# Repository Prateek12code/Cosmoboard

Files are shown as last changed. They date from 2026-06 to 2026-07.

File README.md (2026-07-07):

# Cosmoboard

**Cosmoboard** is a custom 75% mechanical keyboard with an open-top floating-switch design, custom PCB, MX hot-swap support, RGB lighting, and a 3D printed case and plate.

It is designed as a clean V1 keyboard build: simple enough to manufacture, but still custom enough to learn PCB design, keyboard matrices, routing, stabilizer placement, case design, and real hardware assembly.

> Type your ideas into orbit, one key at a time.

---

## Gallery

| PCB | Plate | 3D View |
|---|---|---|
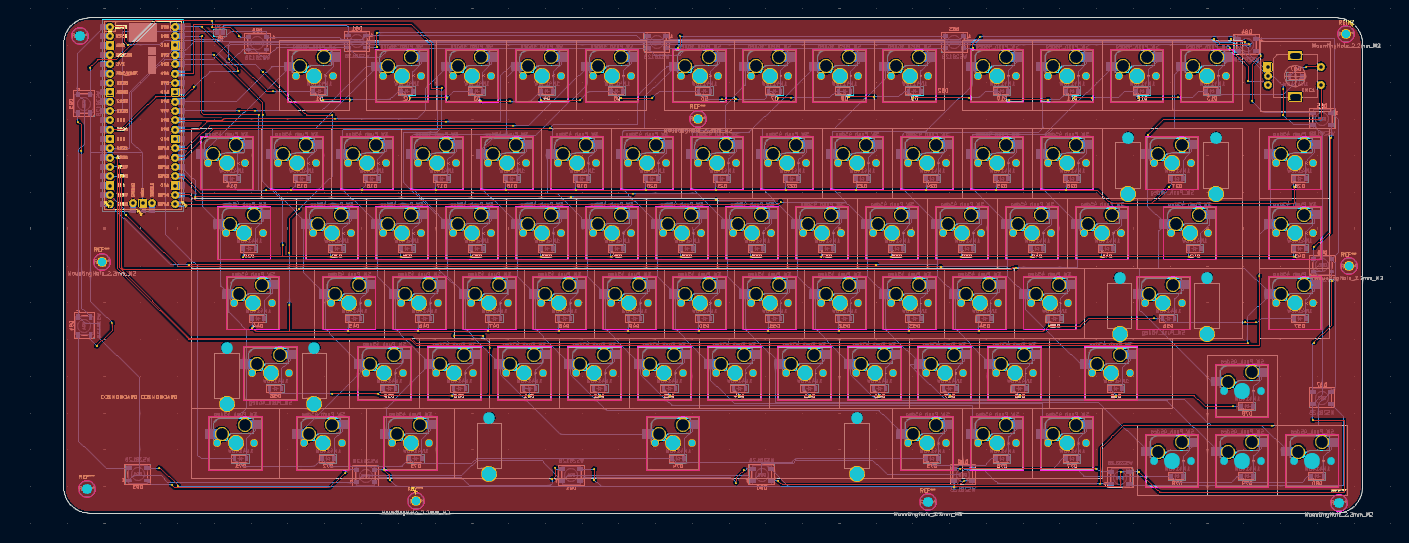
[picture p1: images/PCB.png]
PCB
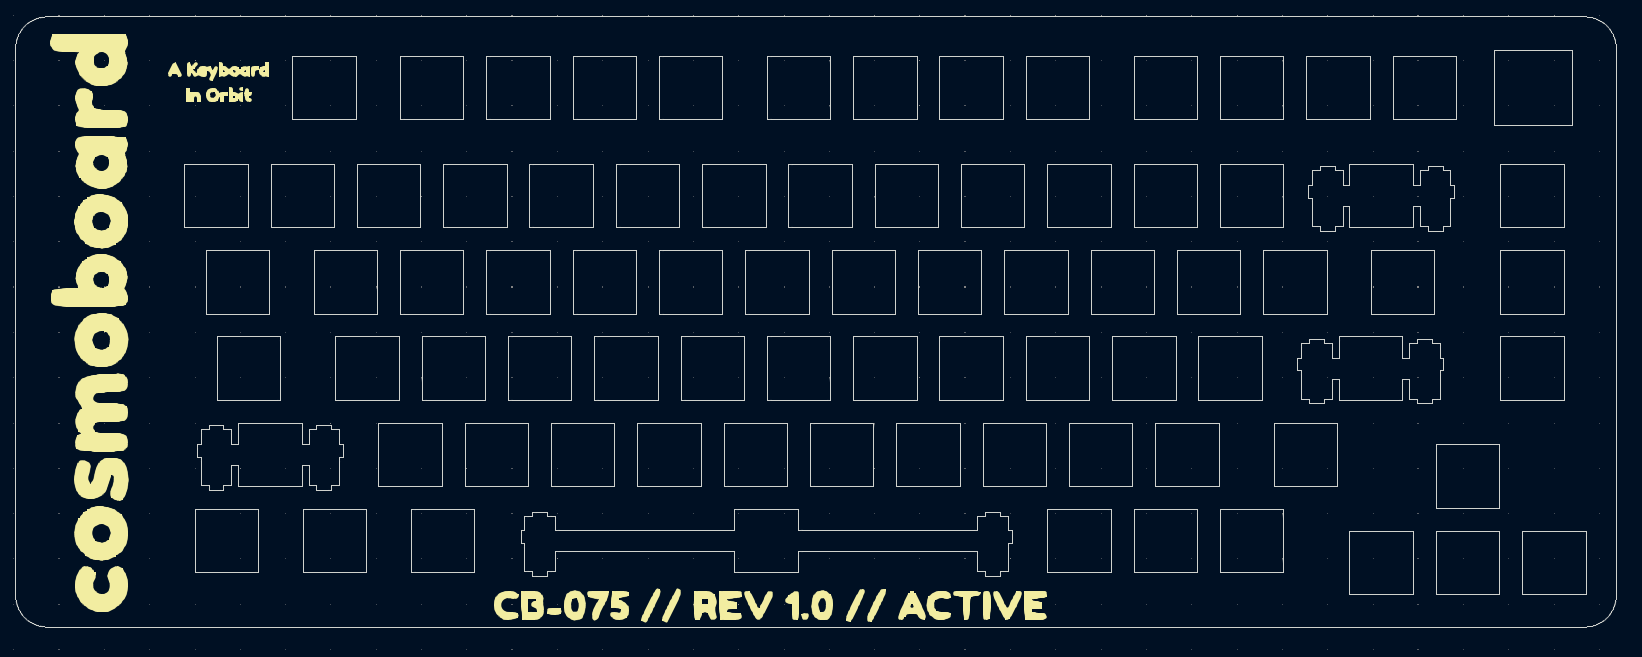
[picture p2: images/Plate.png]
Plate
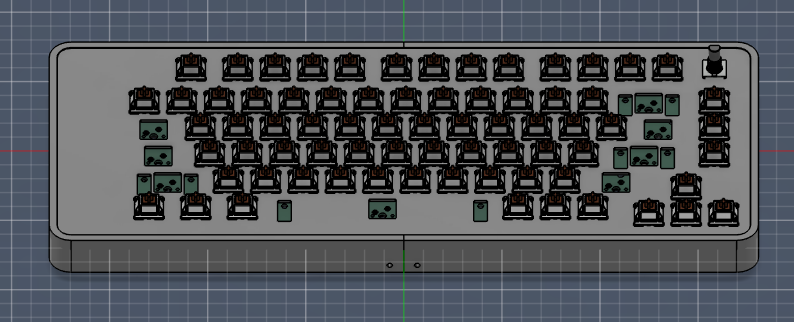
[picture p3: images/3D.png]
3D View
|  |  |  |

---

## Why I Made This

I wanted to design and build my own keyboard from scratch instead of only using prebuilt keyboards.

Cosmoboard started as a learning project, but it slowly became a full custom keyboard design. Through this project, I worked on the keyboard layout, PCB routing, diode matrix, hot-swap sockets, stabilizer placement, case design, plate design, BOM planning, and manufacturing decisions.

The first plan used an FR4 plate, but I later changed it to a **3D printed plate** to reduce the total cost and make the project easier to prototype.

The goal of V1 is simple: make a keyboard that works, looks clean, and teaches me enough to build a better version later.

---

## Features

- Custom 75% keyboard layout
- MX-style mechanical switches
- MX hot-swap sockets
- 1N4148W SOD-123 diodes
- PCB-mount stabilizers
- WS2812B 5050 RGB LEDs
- Custom black PCB
- 3D printed switch plate
- 3D printed case
- Open-top floating-switch style
- Split case design for easier 3D printing
- Designed for real manufacturing and assembly

---

## Hardware Overview

| Part | Selected Item |
|---|---|
| PCB | Custom Cosmoboard PCB from JLCPCB |
| Switches | HMX Macchiato Linear Switches |
| Sockets | Kailh MX Hot-swap Sockets |
| Diodes | 1N4148W SOD-123 Diodes |
| Keycaps | Cherry Colour PBT Keycap Set |
| Stabilizers | Glorious GOAT PCB-mount Stabilizers |
| RGB | Worldsemi WS2812B 5050 LEDs |
| Plate | 3D Printed Plate |
| Case | 3D Printed Split Case |
| Filament | Numakers PLA+ Clear Transparent |

---

## PCB Details

| Item | Value |
|---|---|
| PCB Name | Cosmoboard-PCB_Y12 |
| PCB Width | Around 361.6 mm |
| PCB Thickness | 1.6 mm |
| PCB Color | Black |
| Switch Type | MX-style |
| Socket Type | Kailh MX Hot-swap |
| Diode Package | SOD-123 |
| Plate Type | 3D Printed |
| Case Type | Split 3D Printed Case |

---

## Case And Plate

The keyboard is wider than a normal Bambu Lab A1 build plate, so the case and plate are designed to be split into printable parts.

The case plan includes:

- Split 3D printed frame
- 3D printed switch plate
- Internal support ribs to reduce flex
- PCB screw mounting
- USB cutout
- Open-top floating-switch look

The FR4 plate was removed from the plan to reduce cost. The keyboard now uses a 3D printed plate and case.

---

## Bill Of Materials

The updated BOM is stored in:

```text
production/BOM.csv

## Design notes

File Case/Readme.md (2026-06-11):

# Case / Bottom Tray

Cosmoboard uses an open-top floating-switch design with a bottom tray/base.

The tray will support the PCB and plate stack, expose the controller USB-C port, and use the same 9 mounting holes as the PCB and FR4 plate.

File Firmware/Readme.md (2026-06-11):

# Firmware

Cosmoboard will use QMK/KMK firmware for the WeAct RP2350A controller module.

Firmware is not finalised yet because the PCB is currently in the fabrication stage.

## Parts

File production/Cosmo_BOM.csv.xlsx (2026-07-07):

Category | Item | Description | Qty Required | Qty to Buy | Unit / Pack Qty | Unit Price Currency | Unit Price | Estimated Total INR | Estimated Total USD | Vendor | Product Link | Status
PCB | Custom keyboard PCB | Cosmoboard-PCB_Y12 PCB prototype order | 5 | 5 | 1 | USD | 26.24 | 2492.8 | 26.24 | JLCPCB | https://jlcpcb.com/ | Included
Shipping | JLCPCB shipping | Shipping estimate shown in JLCPCB cart | 1 | 1 | 1 | USD | 23.4 | 2223 | 23.4 | JLCPCB | https://jlcpcb.com/ | Included
Diodes | 1N4148W SOD-123 1206 Diode | Small signal switching diode for keyboard matrix | 100 | 100 | 1 | INR | 0.7 | 70 | 0.74 | Robu.in | https://robu.in/product/1n4148w-sod-123-1206-diodereel-of-3000/ | Included
Case / Plate Material | Numakers PLA+ Clear Transparent 1.75 mm 1 kg spool | Filament for 3D printed case and plate | 1 | 1 | 1 | INR | 780 | 780 | 8.21 | Robu.in | https://robu.in/product/numakers-pla-natural-transparent-1-75-mm-1-kg/ | Included
RGB LEDs | Worldsemi WS2812B-B/W-5050 Addressable RGB LED - SMD | 5050 SMD addressable RGB LED | 20 | 20 | 1 | INR | 8 | 160 | 1.68 | Hubtronics | https://hubtronics.in/ws2812b-b-w-5050-led | Included
Shipping | RGB LED shipping | Shipping shown in LED vendor cart | 1 | 1 | 1 | INR | 118 | 118 | 1.24 | Hubtronics | https://hubtronics.in/ws2812b-b-w-5050-led | Included
Hot-swap Sockets | Kailh Hot-swap Socket | Kailh white MX hot-swap sockets | 80 | 9 | 10 | INR | 76 | 684 | 7.2 | Meckeys | https://meckeys.com/shop/accessories/keyboard-accessories/key-switches/kailh-hot-swap-socket/ | Included
Keycaps | Cherry Colour PBT Keycap Set | PBT keycap set | 1 | 1 | 1 | INR | 1199 | 1199 | 12.62 | Meckeys | https://meckeys.com/shop/accessories/keyboard-accessories/keycaps/cherry-colour-pbt-keycap-set/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 | Included
Stabilizers | Glorious GOAT Stabilizers | PCB mount screw-in stabilizer kit | 1 | 1 | 1 | INR | 999 | 999 | 10.52 | Meckeys | https://meckeys.com/shop/accessories/keyboard-accessories/more/glorious-goat-stabilizers/ | Included
Shipping | Meckeys standard shipping | Standard shipping shown in Meckeys cart | 1 | 1 | 1 | INR | 100 | 100 | 1.05 | Meckeys | https://meckeys.com/ | Included
Switches | HMX Macchiato Linear Switch | MX-style linear switch | 80 | 9 | 10 | INR | 300 | 2700 | 28.42 | Neo Macro | https://neomacro.in/products/hmx-macchiato-linear-switch?variant=48328317993238 | Included
TOTAL | Included BOM Total | Cosmoboard-PCB_Y12 PCB prototype order |  |  |  |  |  | 11525.8 | 121.32 |  |  | Included

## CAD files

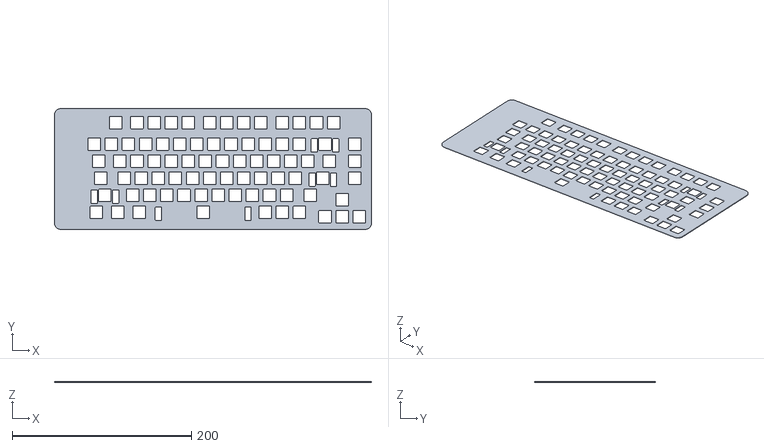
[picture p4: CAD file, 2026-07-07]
Case/COSMOBOARD_PLATE.stl
353.3 x 134.7 x 1.60

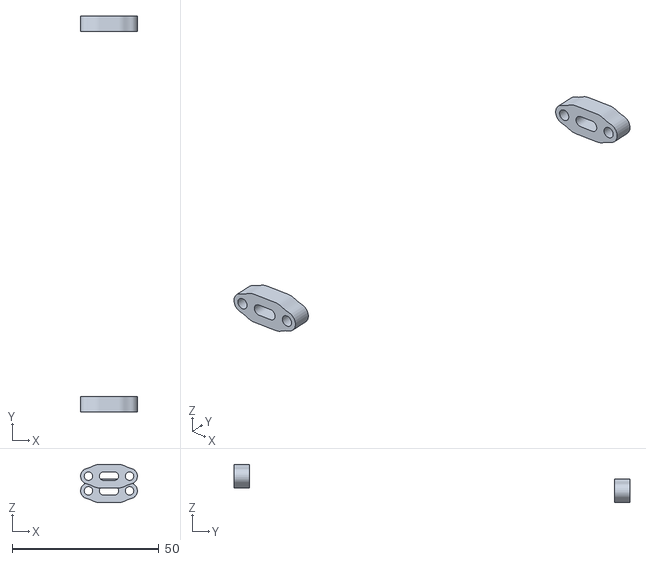
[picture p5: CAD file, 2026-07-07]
Case/COSMOBOARD_JOINTS.stl
19.4 x 135.0 x 13.0

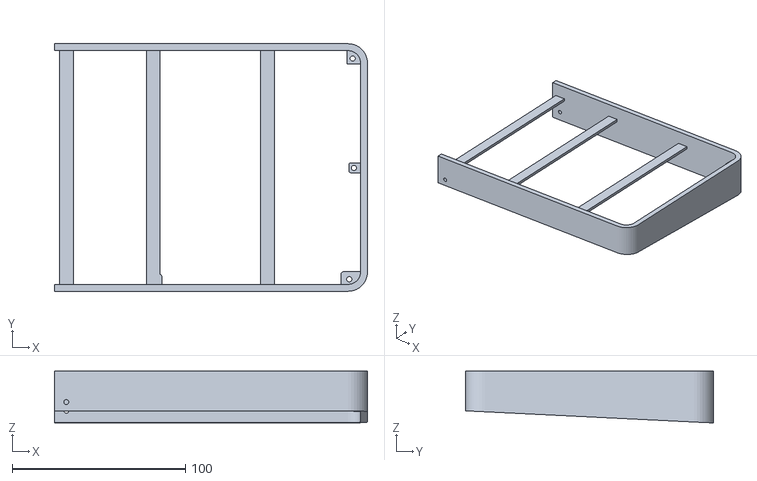
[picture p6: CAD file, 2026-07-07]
Case/COSMOBOARD_RIGHT.stl
180.8 x 143.0 x 30.0

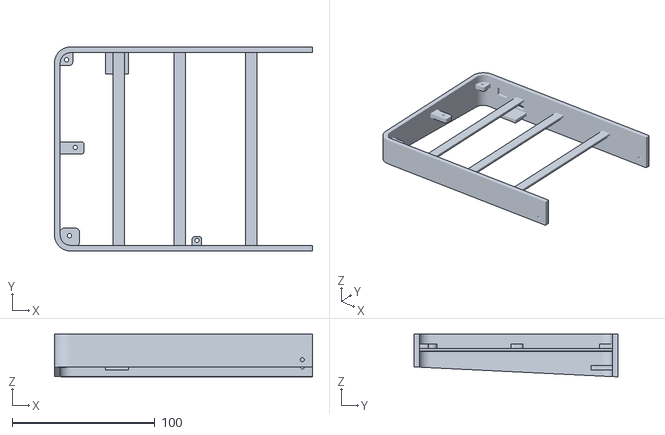
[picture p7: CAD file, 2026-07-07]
Case/COSMOBOARD_LEFT.stl
180.8 x 143.0 x 30.0

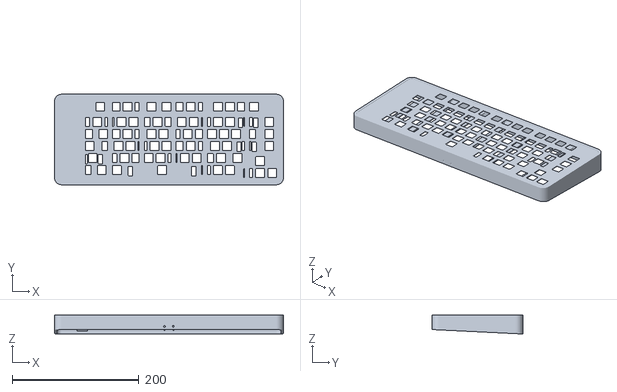
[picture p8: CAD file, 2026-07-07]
Case/COSMOBOARD.stl
361.6 x 143.0 x 30.0

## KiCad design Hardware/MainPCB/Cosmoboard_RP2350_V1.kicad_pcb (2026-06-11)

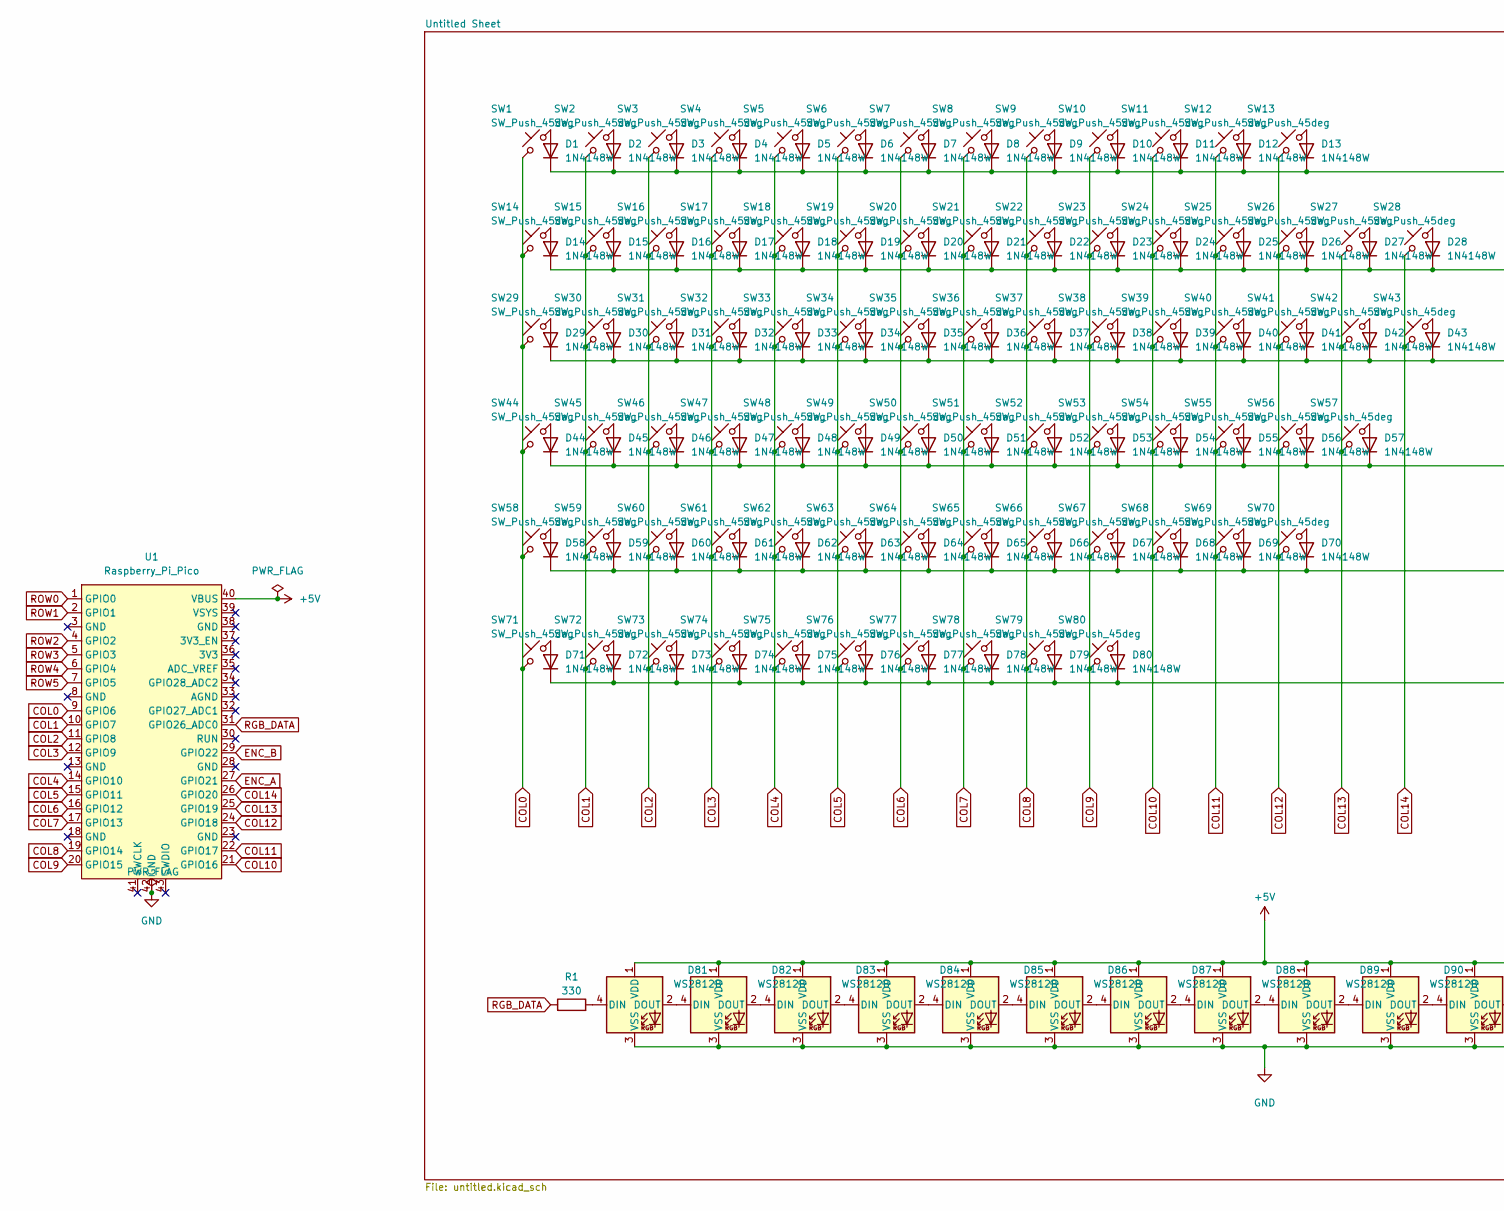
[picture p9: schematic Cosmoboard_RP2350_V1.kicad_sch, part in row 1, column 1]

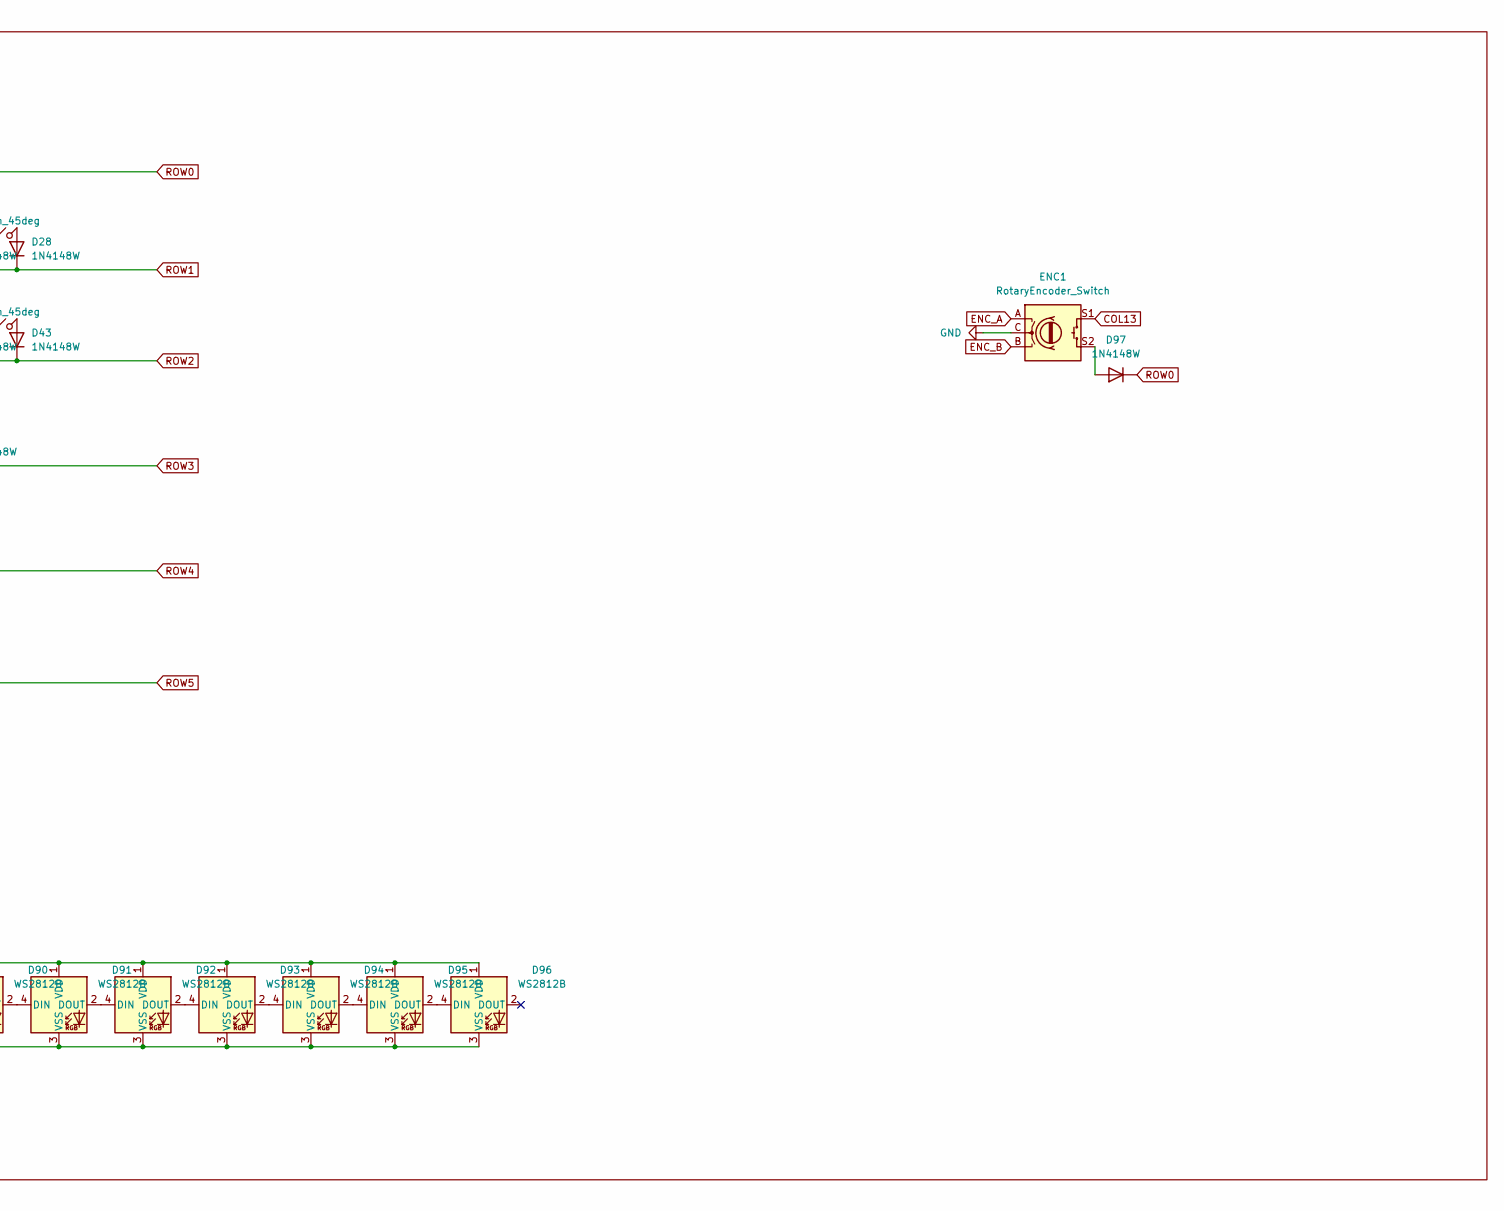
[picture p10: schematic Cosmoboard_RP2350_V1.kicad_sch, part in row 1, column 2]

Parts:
D1, D2, D3, D4, D5, D6, D7, D8, D9, D10, D11, D12, D13, D14, D15, D16, D17, D18, D19, D20, D21, D22, D23, D24, D25, D26, D27, D28, D29, D30, D31, D32, D33, D34, D35, D36, D37, D38, D39, D40, D41, D42, D43, D44, D45, D46, D47, D48, D49, D50, D51, D52, D53, D54, D55, D56, D57, D58, D59, D60, D61, D62, D63, D64, D65, D66, D67, D68, D69, D70, D71, D72, D73, D74, D75, D76, D77, D78, D79, D80, D97: 1N4148W; D_SOD-123
D81, D82, D83, D84, D85, D86, D87, D88, D89, D90, D91, D92, D93, D94, D95, D96: WS2812B; LED_WS2812B_PLCC4_5.0x5.0mm_P3.2mm
ENC1: RotaryEncoder_Switch; Encoder_EC11_MX
R1: 330; R_0805_2012Metric
SW1, SW2, SW3, SW4, SW5, SW6, SW7, SW8, SW9, SW10, SW11, SW12, SW13, SW14, SW15, SW16, SW17, SW18, SW19, SW20, SW21, SW22, SW23, SW24, SW25, SW26, SW28, SW30, SW31, SW32, SW33, SW34, SW35, SW36, SW37, SW38, SW39, SW40, SW41, SW43, SW45, SW46, SW47, SW48, SW49, SW50, SW51, SW52, SW53, SW54, SW55, SW57, SW59, SW60, SW61, SW62, SW63, SW64, SW65, SW66, SW67, SW68, SW70, SW75, SW76, SW77, SW78, SW79, SW80: SW_Push_45deg; MX_Hotswap_1.00u
SW27: SW_Push_45deg; MX_Hotswap_2.00u
SW29, SW42: SW_Push_45deg; MX_Hotswap_1.50u
SW44, SW69: SW_Push_45deg; MX_Hotswap_1.75u
SW56, SW58: SW_Push_45deg; MX_Hotswap_2.25u
SW71, SW72, SW73: SW_Push_45deg; MX_Hotswap_1.25u
SW74: SW_Push_45deg; MX_Hotswap_6.25u
U1: Raspberry_Pi_Pico

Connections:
+5V: D81.1 (VDD), D82.1 (VDD), D83.1 (VDD), D84.1 (VDD), D85.1 (VDD), D86.1 (VDD), D87.1 (VDD), D88.1 (VDD), D89.1 (VDD), D90.1 (VDD), D91.1 (VDD), D92.1 (VDD), D93.1 (VDD), D94.1 (VDD), D95.1 (VDD), D96.1 (VDD), U1.40 (VBUS)
COL0: SW1.1, SW14.1, SW29.1, SW44.1, SW58.1, SW71.1, U1.9 (GPIO6)
COL1: SW2.1, SW15.1, SW30.1, SW45.1, SW59.1, SW72.1, U1.10 (GPIO7)
COL2: SW3.1, SW16.1, SW31.1, SW46.1, SW60.1, SW73.1, U1.11 (GPIO8)
COL3: SW4.1, SW17.1, SW32.1, SW47.1, SW61.1, SW74.1, U1.12 (GPIO9)
COL4: SW5.1, SW18.1, SW33.1, SW48.1, SW62.1, SW75.1, U1.14 (GPIO10)
COL5: SW6.1, SW19.1, SW34.1, SW49.1, SW63.1, SW76.1, U1.15 (GPIO11)
COL6: SW7.1, SW20.1, SW35.1, SW50.1, SW64.1, SW77.1, U1.16 (GPIO12)
COL7: SW8.1, SW21.1, SW36.1, SW51.1, SW65.1, SW78.1, U1.17 (GPIO13)
COL8: SW9.1, SW22.1, SW37.1, SW52.1, SW66.1, SW79.1, U1.19 (GPIO14)
COL9: SW10.1, SW23.1, SW38.1, SW53.1, SW67.1, SW80.1, U1.20 (GPIO15)
COL10: SW11.1, SW24.1, SW39.1, SW54.1, SW68.1, U1.21 (GPIO16)
COL11: SW12.1, SW25.1, SW40.1, SW55.1, SW69.1, U1.22 (GPIO17)
COL12: SW13.1, SW26.1, SW41.1, SW56.1, SW70.1, U1.24 (GPIO18)
COL13: ENC1.S1, SW27.1, SW42.1, SW57.1, U1.25 (GPIO19)
COL14: SW28.1, SW43.1, U1.26 (GPIO20)
ENC_A: ENC1.A, U1.27 (GPIO21)
ENC_B: ENC1.B, U1.29 (GPIO22)
GND: D81.3 (VSS), D82.3 (VSS), D83.3 (VSS), D84.3 (VSS), D85.3 (VSS), D86.3 (VSS), D87.3 (VSS), D88.3 (VSS), D89.3 (VSS), D90.3 (VSS), D91.3 (VSS), D92.3 (VSS), D93.3 (VSS), D94.3 (VSS), D95.3 (VSS), D96.3 (VSS), ENC1.C, U1.42 (GND)
unnamed: D1.2 (A), SW1.2
unnamed: D2.2 (A), SW2.2
unnamed: D3.2 (A), SW3.2
unnamed: D4.2 (A), SW4.2
unnamed: D5.2 (A), SW5.2
unnamed: D6.2 (A), SW6.2
unnamed: D7.2 (A), SW7.2
unnamed: D8.2 (A), SW8.2
unnamed: D9.2 (A), SW9.2
unnamed: D10.2 (A), SW10.2
unnamed: D11.2 (A), SW11.2
unnamed: D12.2 (A), SW12.2
unnamed: D13.2 (A), SW13.2
unnamed: D14.2 (A), SW14.2
unnamed: D15.2 (A), SW15.2
unnamed: D16.2 (A), SW16.2
unnamed: D17.2 (A), SW17.2
unnamed: D18.2 (A), SW18.2
unnamed: D19.2 (A), SW19.2
unnamed: D20.2 (A), SW20.2
unnamed: D21.2 (A), SW21.2
unnamed: D22.2 (A), SW22.2
unnamed: D23.2 (A), SW23.2
unnamed: D24.2 (A), SW24.2
unnamed: D25.2 (A), SW25.2
unnamed: D26.2 (A), SW26.2
unnamed: D27.2 (A), SW27.2
unnamed: D28.2 (A), SW28.2
unnamed: D29.2 (A), SW29.2
unnamed: D30.2 (A), SW30.2
unnamed: D31.2 (A), SW31.2
unnamed: D32.2 (A), SW32.2
unnamed: D33.2 (A), SW33.2
unnamed: D34.2 (A), SW34.2
unnamed: D35.2 (A), SW35.2
unnamed: D36.2 (A), SW36.2
unnamed: D37.2 (A), SW37.2
unnamed: D38.2 (A), SW38.2
unnamed: D39.2 (A), SW39.2
unnamed: D40.2 (A), SW40.2
unnamed: D41.2 (A), SW41.2
unnamed: D42.2 (A), SW42.2
unnamed: D43.2 (A), SW43.2
unnamed: D44.2 (A), SW44.2
unnamed: D45.2 (A), SW45.2
unnamed: D46.2 (A), SW46.2
unnamed: D47.2 (A), SW47.2
unnamed: D48.2 (A), SW48.2
unnamed: D49.2 (A), SW49.2
unnamed: D50.2 (A), SW50.2
unnamed: D51.2 (A), SW51.2
unnamed: D52.2 (A), SW52.2
unnamed: D53.2 (A), SW53.2
unnamed: D54.2 (A), SW54.2
unnamed: D55.2 (A), SW55.2
unnamed: D56.2 (A), SW56.2
unnamed: D57.2 (A), SW57.2
unnamed: D58.2 (A), SW58.2
unnamed: D59.2 (A), SW59.2
unnamed: D60.2 (A), SW60.2
unnamed: D61.2 (A), SW61.2
unnamed: D62.2 (A), SW62.2
unnamed: D63.2 (A), SW63.2
unnamed: D64.2 (A), SW64.2
unnamed: D65.2 (A), SW65.2
unnamed: D66.2 (A), SW66.2
unnamed: D67.2 (A), SW67.2
unnamed: D68.2 (A), SW68.2
unnamed: D69.2 (A), SW69.2
unnamed: D70.2 (A), SW70.2
unnamed: D71.2 (A), SW71.2
unnamed: D72.2 (A), SW72.2
unnamed: D73.2 (A), SW73.2
unnamed: D74.2 (A), SW74.2
unnamed: D75.2 (A), SW75.2
unnamed: D76.2 (A), SW76.2
unnamed: D77.2 (A), SW77.2
unnamed: D78.2 (A), SW78.2
unnamed: D79.2 (A), SW79.2
unnamed: D80.2 (A), SW80.2
unnamed: D81.4 (DIN), R1.2
unnamed: D81.2 (DOUT), D82.4 (DIN)
unnamed: D82.2 (DOUT), D83.4 (DIN)
unnamed: D83.2 (DOUT), D84.4 (DIN)
unnamed: D84.2 (DOUT), D85.4 (DIN)
unnamed: D85.2 (DOUT), D86.4 (DIN)
unnamed: D86.2 (DOUT), D87.4 (DIN)
unnamed: D87.2 (DOUT), D88.4 (DIN)
unnamed: D88.2 (DOUT), D89.4 (DIN)
unnamed: D89.2 (DOUT), D90.4 (DIN)
unnamed: D90.2 (DOUT), D91.4 (DIN)
unnamed: D91.2 (DOUT), D92.4 (DIN)
unnamed: D92.2 (DOUT), D93.4 (DIN)
unnamed: D93.2 (DOUT), D94.4 (DIN)
unnamed: D94.2 (DOUT), D95.4 (DIN)
unnamed: D95.2 (DOUT), D96.4 (DIN)
unnamed: D97.2 (A), ENC1.S2
RGB_DATA: R1.1, U1.31 (GPIO26_ADC0)
ROW0: D1.1 (K), D2.1 (K), D3.1 (K), D4.1 (K), D5.1 (K), D6.1 (K), D7.1 (K), D8.1 (K), D9.1 (K), D10.1 (K), D11.1 (K), D12.1 (K), D13.1 (K), D97.1 (K), U1.1 (GPIO0)
ROW1: D14.1 (K), D15.1 (K), D16.1 (K), D17.1 (K), D18.1 (K), D19.1 (K), D20.1 (K), D21.1 (K), D22.1 (K), D23.1 (K), D24.1 (K), D25.1 (K), D26.1 (K), D27.1 (K), D28.1 (K), U1.2 (GPIO1)
ROW2: D29.1 (K), D30.1 (K), D31.1 (K), D32.1 (K), D33.1 (K), D34.1 (K), D35.1 (K), D36.1 (K), D37.1 (K), D38.1 (K), D39.1 (K), D40.1 (K), D41.1 (K), D42.1 (K), D43.1 (K), U1.4 (GPIO2)
ROW3: D44.1 (K), D45.1 (K), D46.1 (K), D47.1 (K), D48.1 (K), D49.1 (K), D50.1 (K), D51.1 (K), D52.1 (K), D53.1 (K), D54.1 (K), D55.1 (K), D56.1 (K), D57.1 (K), U1.5 (GPIO3)
ROW4: D58.1 (K), D59.1 (K), D60.1 (K), D61.1 (K), D62.1 (K), D63.1 (K), D64.1 (K), D65.1 (K), D66.1 (K), D67.1 (K), D68.1 (K), D69.1 (K), D70.1 (K), U1.6 (GPIO4)
ROW5: D71.1 (K), D72.1 (K), D73.1 (K), D74.1 (K), D75.1 (K), D76.1 (K), D77.1 (K), D78.1 (K), D79.1 (K), D80.1 (K), U1.7 (GPIO5)

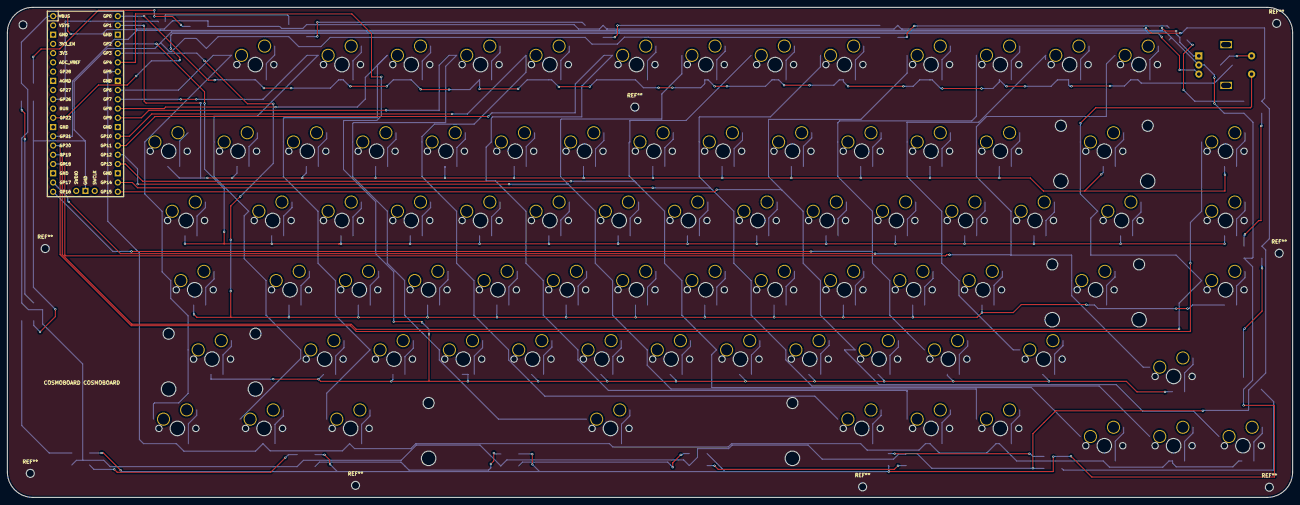
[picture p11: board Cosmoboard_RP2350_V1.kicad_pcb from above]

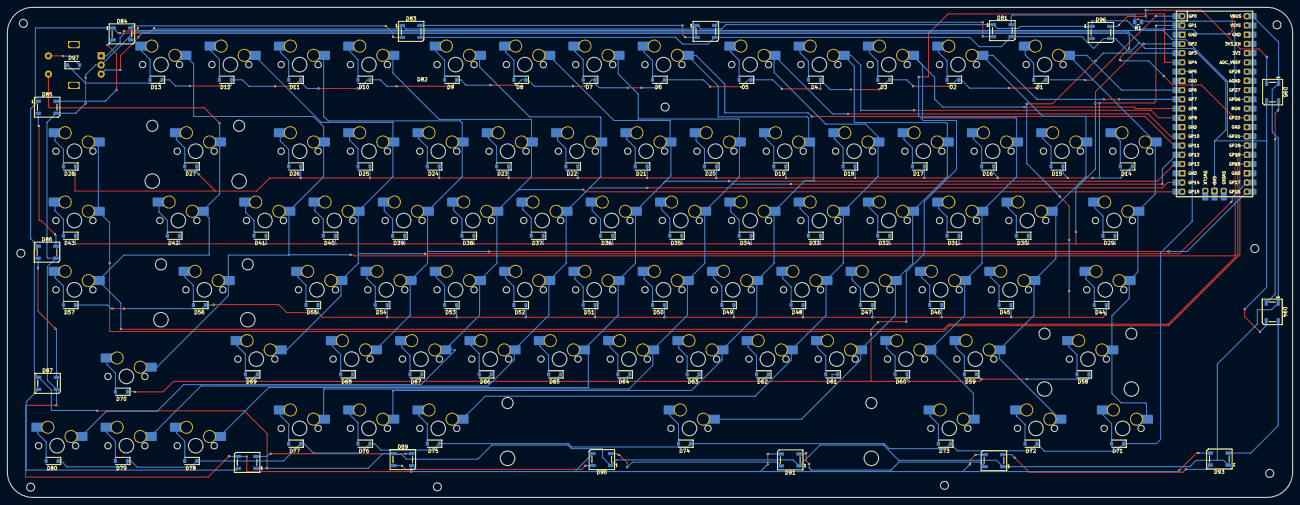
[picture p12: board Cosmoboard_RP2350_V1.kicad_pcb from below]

Board: 2 copper layers, 353.3 x 134.7 mm, 180 parts (179 on the bottom side), 123 nets.

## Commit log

2026-06-07 Rename Screenshot 2026-06-07 161714.png to PCB.png
2026-06-07 Rename Screenshot 2026-06-07 161739.png to Plate.png
2026-06-11 Add initial README for Case / Bottom Tray
